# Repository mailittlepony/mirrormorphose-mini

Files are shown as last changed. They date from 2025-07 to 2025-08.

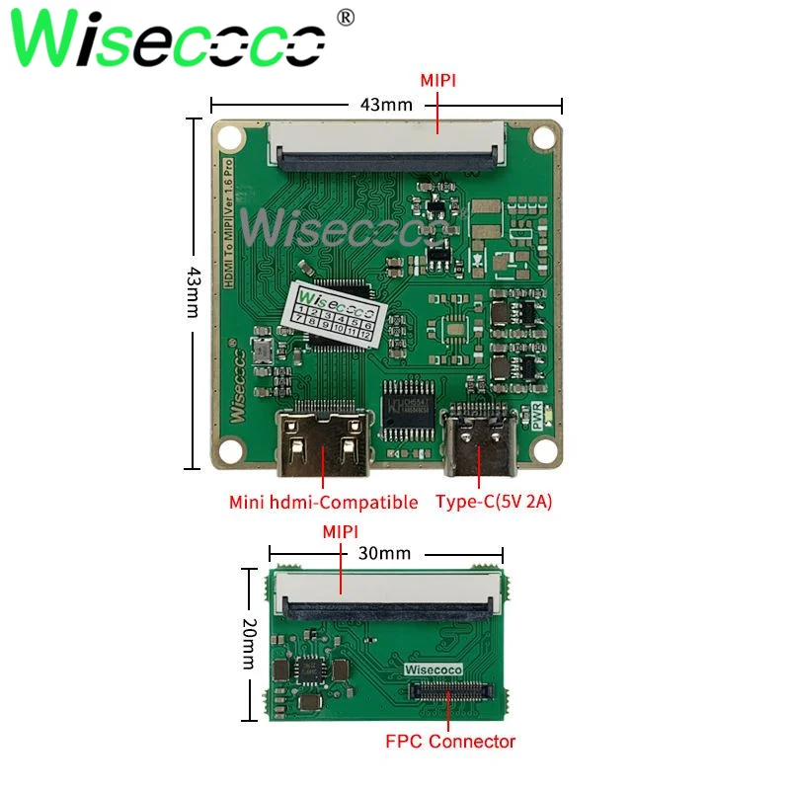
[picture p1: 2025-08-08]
hardware/kicad/display_hdmi_controller/S2047f3f1c8974a16a373eea748ecceee4.webp

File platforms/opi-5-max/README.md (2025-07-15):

This is the platform dependant set up script.

Hardware:
- Orange Pi 5 Max 8GB | Rockchip RK3588 1.8/2.4 GHz | 8 cores | ARMv8
- 5'5 1080x1920 AMOLED HDMI screen
- Orange Pi camera 120° (OV13855)
- SD card

OS:
- DietPi for Orange Pi 5 Max

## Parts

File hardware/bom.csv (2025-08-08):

Item | URL | Quantity | Price Per Unit | Total Price | Vendor
Orange pi 5B max 8GB | https://www.aliexpress.com/item/1005007870048287.html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: | 1 | 18632 | 18632 | Aliexpress
5.5” OLED Full HD screen (option: Full set) | https://ja.aliexpress.com/item/1005004285318699.html?src=google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 | 1 | 10537 | 10537 | Aliexpress
Orange pi camera 80-FF-200mm | https://www.aliexpress.com/item/1005009077854077.html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 | 1 | 3431 | 3431 | Aliexpress
Polyurethane resin 500ml | https://ja.aliexpress.com/item/1005007086008107.html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: | 1 | 2599 | 2599 | Aliexpress
2x 3007 Blower 5V 1W (option 5V- xh2.54) | https://ja.aliexpress.com/item/1005003167479036.html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: | 1 | 1283 | 1283 | Aliexpress
LTC3780 Buck Boost 10A | https://ja.aliexpress.com/item/1005007384626696.html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: | 1 | 1036 | 1036 | Aliexpress
2x 18650 lipo 3.6V 4000mAh | https://ja.aliexpress.com/item/1005006454038524.html?gatewayAdapt=glo2jpn | 1 | 1021 | 1021 | Aliexpress
10x LTC4412 (for power path) | https://ja.aliexpress.com/item/4000112160576.html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: | 1 | 640 | 640 | Aliexpress
25x25x7 Copper Heatsink + pad | https://ja.aliexpress.com/item/1005005311492799.html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: | 1 | 600 | 600 | Aliexpress
10x IRF4905 P-MOSFET-55V -74A 0.02Ohms | https://ja.aliexpress.com/item/1005007142611635.html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: | 1 | 579 | 579 | Aliexpress
HDMI micro connector (option C1) | https://ja.aliexpress.com/item/1005006437300837.html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: | 1 | 434 | 434 | Aliexpress
HDMI connector (option A1) | https://ja.aliexpress.com/item/1005006437300837.html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: | 1 | 430 | 430 | Aliexpress
HDMI ribbon 10cm | https://ja.aliexpress.com/item/1005006437300837.html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: | 1 | 430 | 430 | Aliexpress
SD card 32GB | https://ja.aliexpress.com/item/1005008332881986.html?scm_id=1007.14452.396806.0&scm-url=1007.14452.396806.0 | 1 | 353 | 353 | Aliexpress
Ribbon cable P0.5, 50P, 20cm, reverse direction | https://ja.aliexpress.com/item/1005007079319126.html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: | 1 | 277 | 277 | Aliexpress
100x M2 14mm screw (countersunk head) | https://ja.aliexpress.com/item/33043885403.html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: | 1 | 277 | 277 | Aliexpress
100x M1.2 5mm screw (pan head) | https://ja.aliexpress.com/item/33043885403.html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: | 1 | 233 | 233 | Aliexpress
USB C PD Trigger 20v | https://ja.aliexpress.com/item/1005005461879717.html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: | 1 | 229 | 229 | Aliexpress
2S 20A Balanced BMS | https://ja.aliexpress.com/item/1005006041486774.html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: | 1 | 220 | 220 | Aliexpress
Lipo charger 3A 2S 5-28V input (IP2364) | https://ja.aliexpress.com/item/1005007817048390.html?gatewayAdapt=glo2jpn | 1 | 200 | 200 | Aliexpress

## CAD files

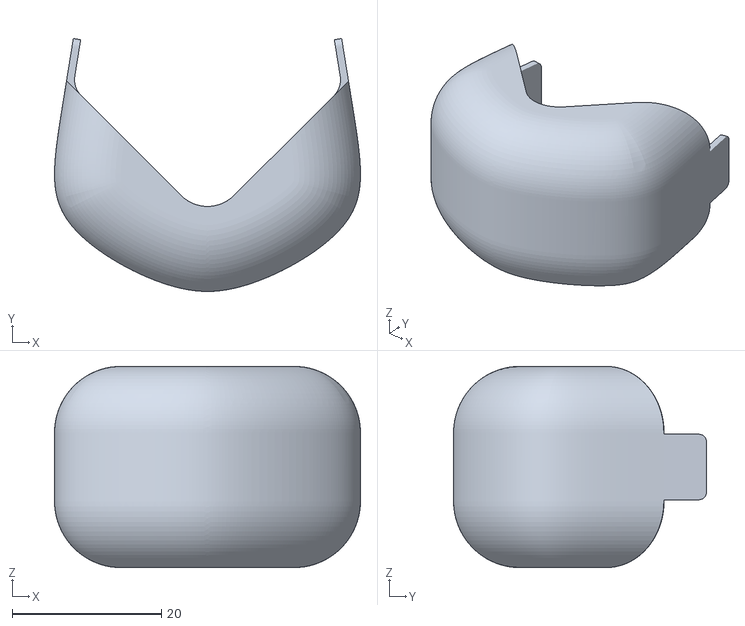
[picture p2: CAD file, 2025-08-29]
hardware/cad/toe.stl
41.1 x 33.9 x 27.0

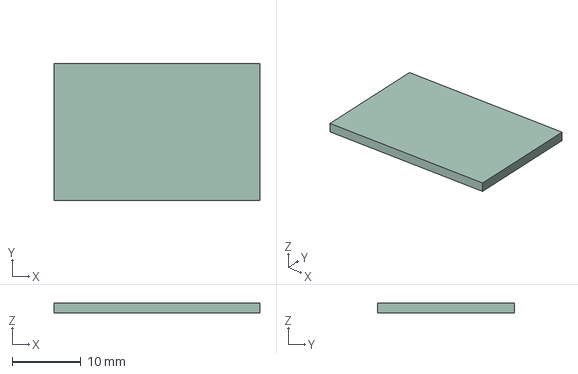
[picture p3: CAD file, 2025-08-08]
hardware/kicad/display_adaptor/display_adaptor.step
30.0 x 20.0 x 1.51 mm

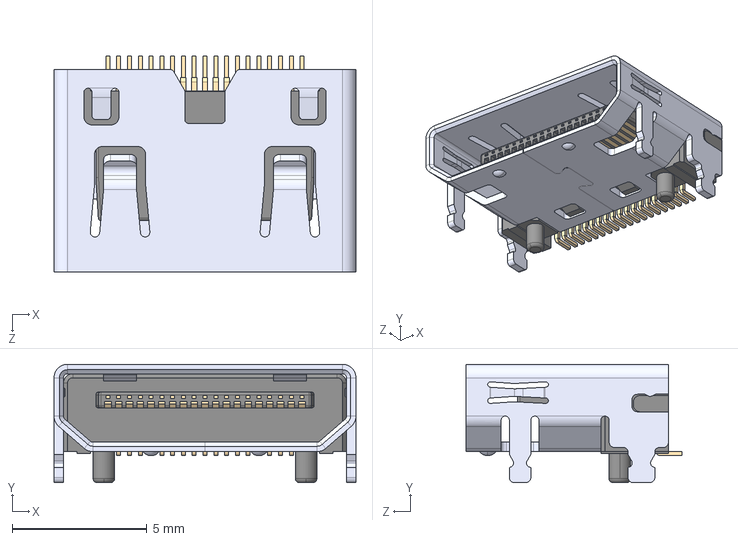
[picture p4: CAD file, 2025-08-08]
hardware/kicad/display_hdmi_controller/3dmodels/690-019-298-903.step
11.2 x 4.39 x 8.00 mm

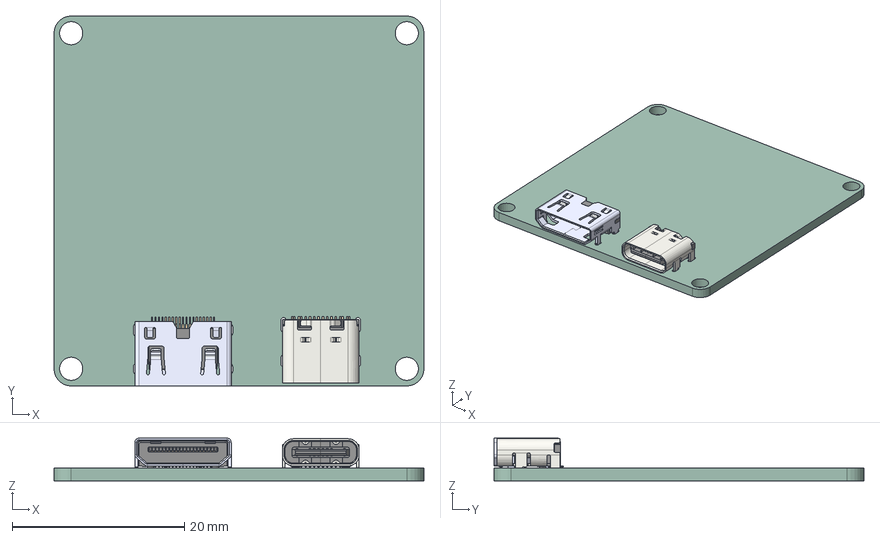
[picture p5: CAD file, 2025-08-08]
hardware/kicad/display_hdmi_controller/display_hdmi_controller.step
43.0 x 43.0 x 4.99 mm
USB_C_Receptacle_GCT_USB4105-xx-A_16P_TopMnt_Horizontal
hdmi_display_kicad_PCB

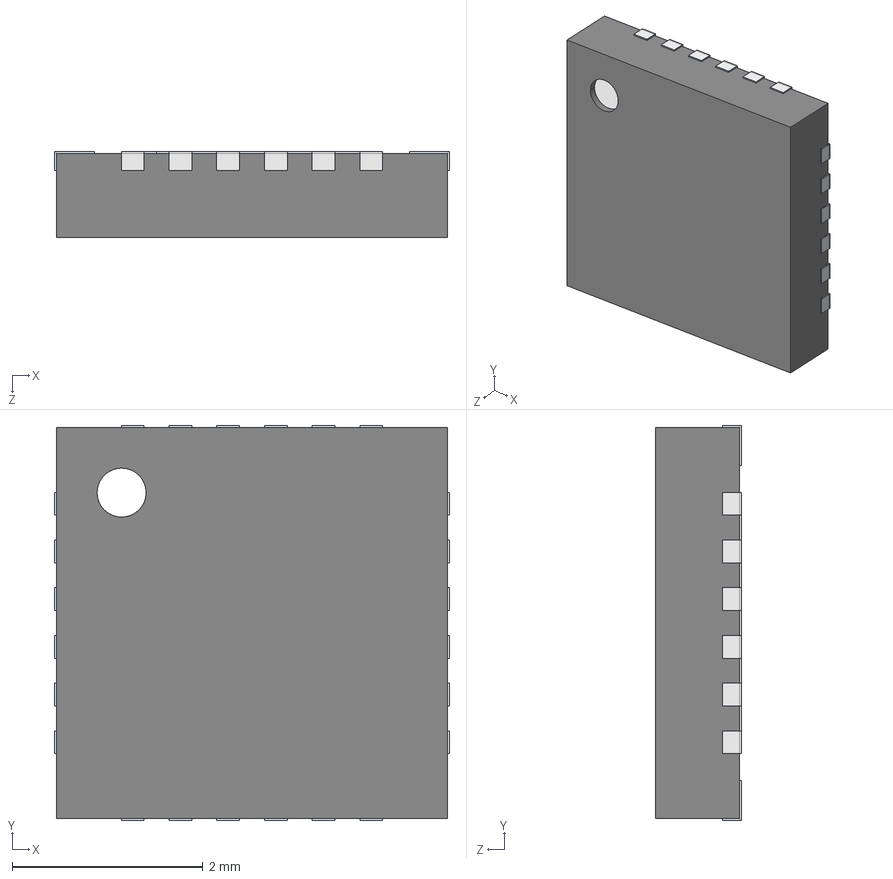
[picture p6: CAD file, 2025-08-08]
hardware/kicad/ip2565charger/3dmodels/QFN 24.STEP
4.14 x 4.14 x 0.9 mm
Open_CASCADE_STEP_translator_6.8_11.2.1.step_Varsay考an
Open_CASCADE_STEP_translator_6.8_11.4.1.step_Varsay考an x 24
Open_CASCADE_STEP_translator_6.8_11.1.step_Varsay考an
Thermal_Shape.step_Varsay考an

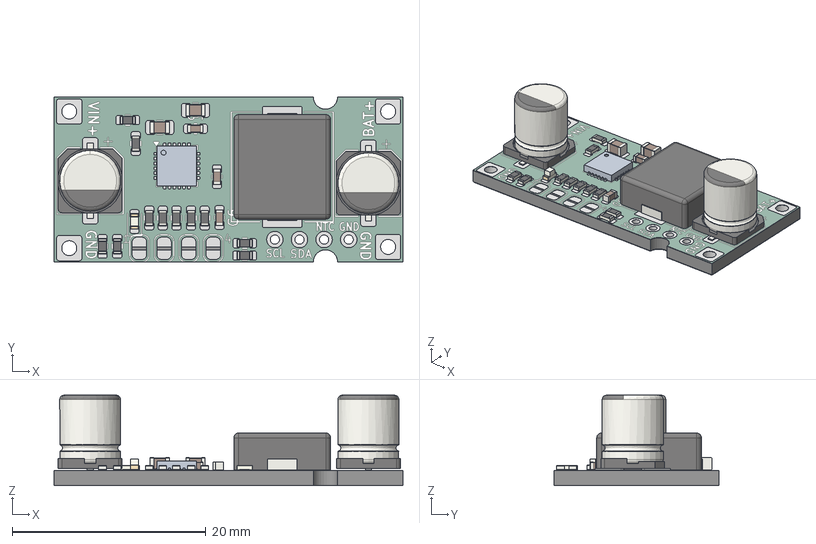
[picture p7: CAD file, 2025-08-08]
hardware/kicad/ip2565charger/ip2565-module.step
36.0 x 17.0 x 9.35 mm
R_0603_1608Metric x 11
CP_Elec_6.3x7.7 x 2
ip2565-module 1.4.1
C_0805_2012Metric x 2
L_APV_APH1040
C_0603_1608Metric x 3
LED_0603_1608Metric
ip2565-module_pad
ip2565-module_silkscreen
ip2565-module_soldermask
ip2565-module_PCB

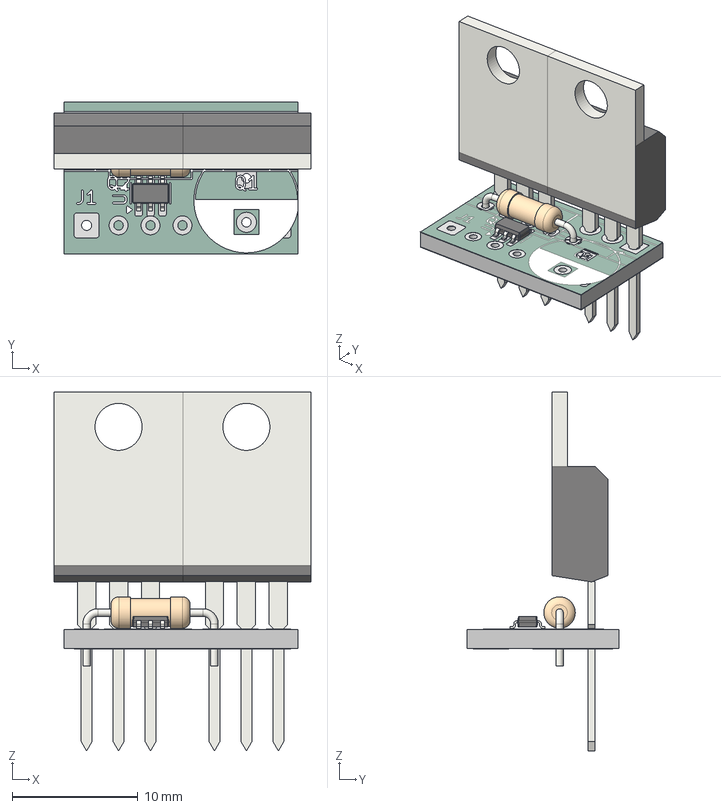
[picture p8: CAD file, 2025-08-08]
hardware/kicad/loadsharing/loadsharing.step
20.4 x 12.1 x 28.5 mm
TSOT-23-6
TO-220-3_Vertical x 2
R_Axial_DIN0207_L6.3mm_D2.5mm_P10.16mm_Horizontal
mirrorminiv2_copper
mirrorminiv2_pad
mirrorminiv2_silkscreen
mirrorminiv2_soldermask
mirrorminiv2_PCB

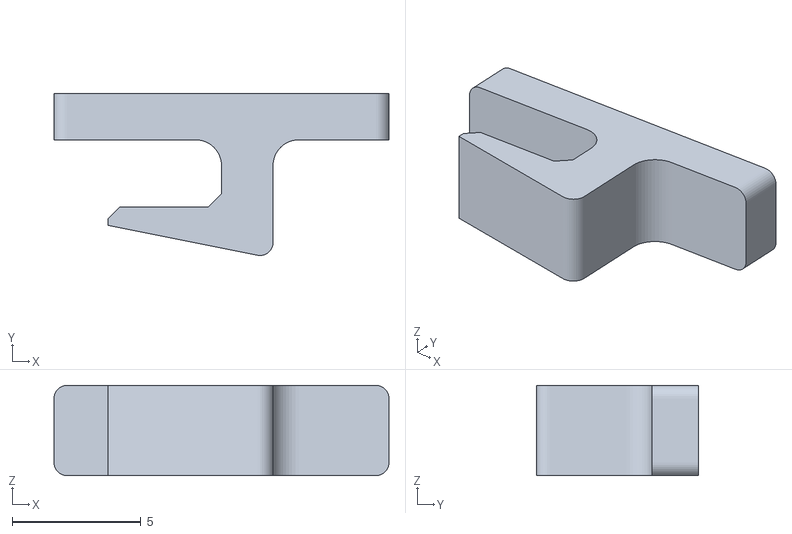
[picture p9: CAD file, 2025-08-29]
hardware/cad/snap-male-smooth.stl
13.0 x 6.29 x 3.50

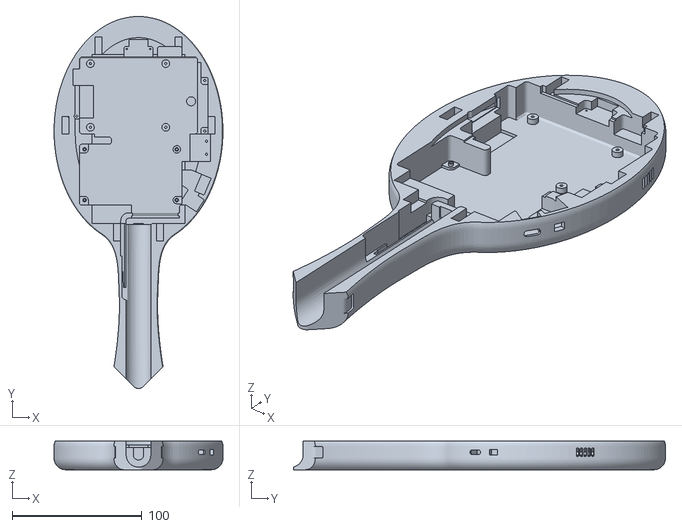
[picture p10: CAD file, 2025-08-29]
hardware/cad/bottom.stl
130.0 x 286.3 x 22.0

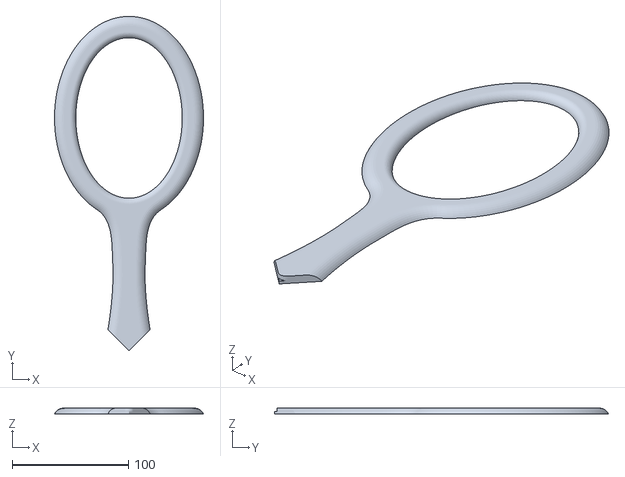
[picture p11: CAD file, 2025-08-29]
hardware/cad/top.stl
128.2 x 287.4 x 5.00

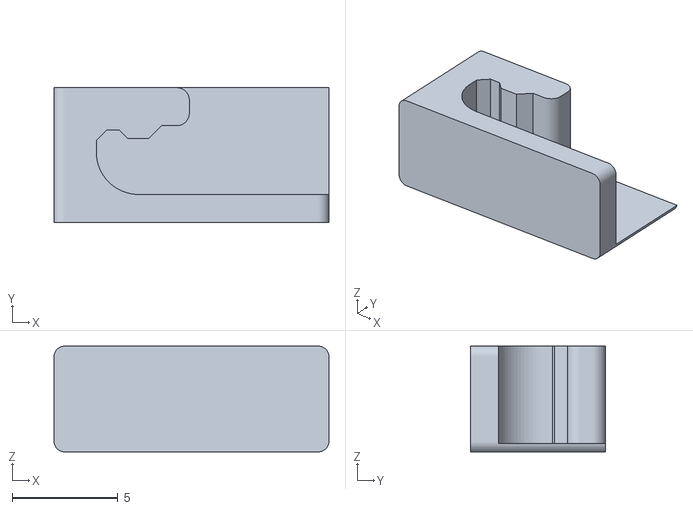
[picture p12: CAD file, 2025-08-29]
hardware/cad/snap-static.stl
13.0 x 6.37 x 5.00

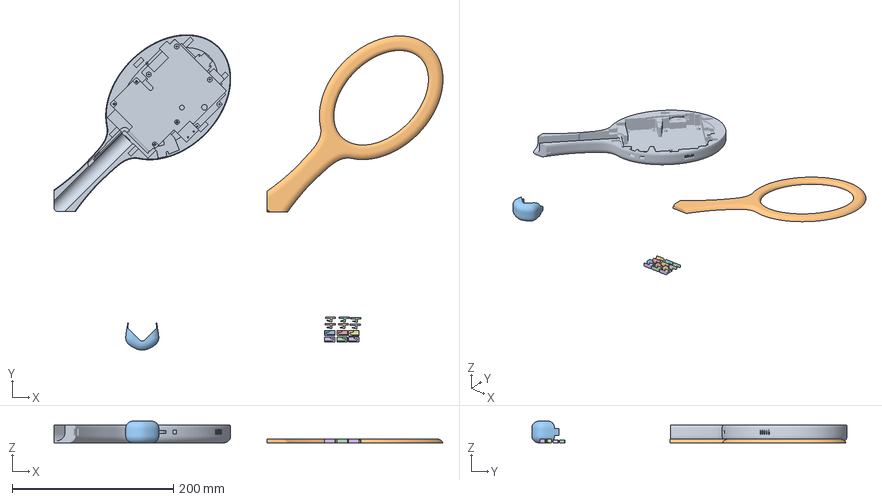
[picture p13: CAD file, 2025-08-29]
hardware/cad/mirrormini_ender3v3ke_orca.3mf
482.0 x 390.9 x 27.0 mm
bottom.stl
top.stl
toe.stl
snap-male-smooth.stl x 4
snap-male.stl x 2
snap-static.stl x 6

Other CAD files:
hardware/cad/snap-male.stl

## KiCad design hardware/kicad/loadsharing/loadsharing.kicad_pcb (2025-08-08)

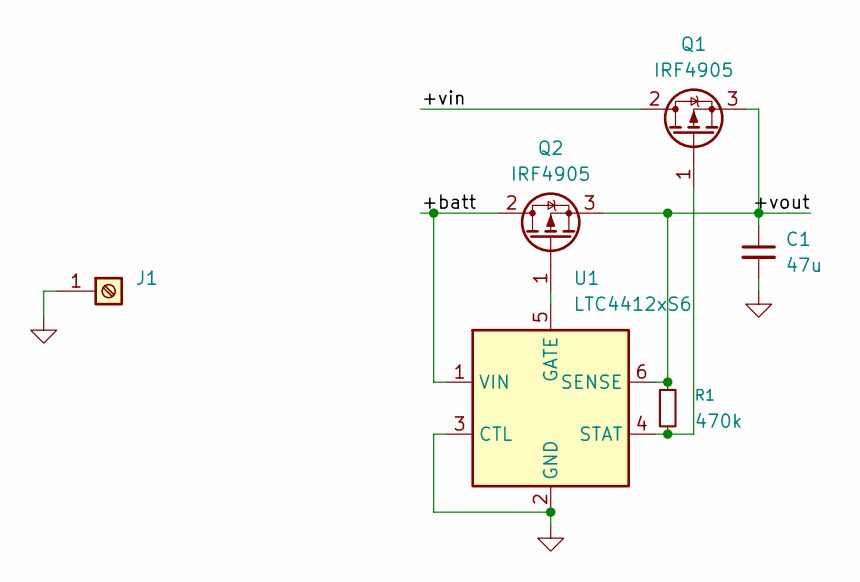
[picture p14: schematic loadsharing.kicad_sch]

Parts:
C1: 47u; CP_Radial_D8.0mm_P3.50mm
J1: Screw_Terminal_01x01; SolderWire-0.25sqmm_1x01_D0.65mm_OD2mm
Q1, Q2: IRF4905; TO-220-3_Vertical
R1: 470k; R_Axial_DIN0207_L6.3mm_D2.5mm_P10.16mm_Horizontal
U1: LTC4412xS6; TSOT-23-6

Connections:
/+batt: Q2.2 (D), U1.1 (VIN)
/+vin: Q1.2 (D)
/+vout: C1.1, Q1.3 (S), Q2.3 (S), R1.1, U1.6 (SENSE)
GND: C1.2, J1.1, U1.2 (GND), U1.3 (CTL)
unnamed: Q1.1 (G), R1.2, U1.4 (STAT)
unnamed: Q2.1 (G), U1.5 (GATE)

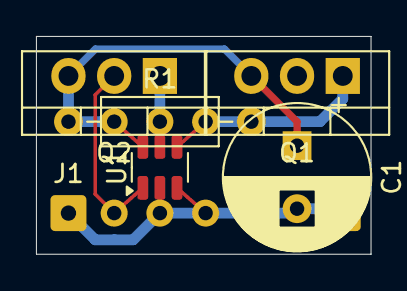
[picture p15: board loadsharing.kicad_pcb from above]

Board: 2 copper layers, 18.6 x 12.1 mm, 6 parts (0 on the bottom side), 5 nets.

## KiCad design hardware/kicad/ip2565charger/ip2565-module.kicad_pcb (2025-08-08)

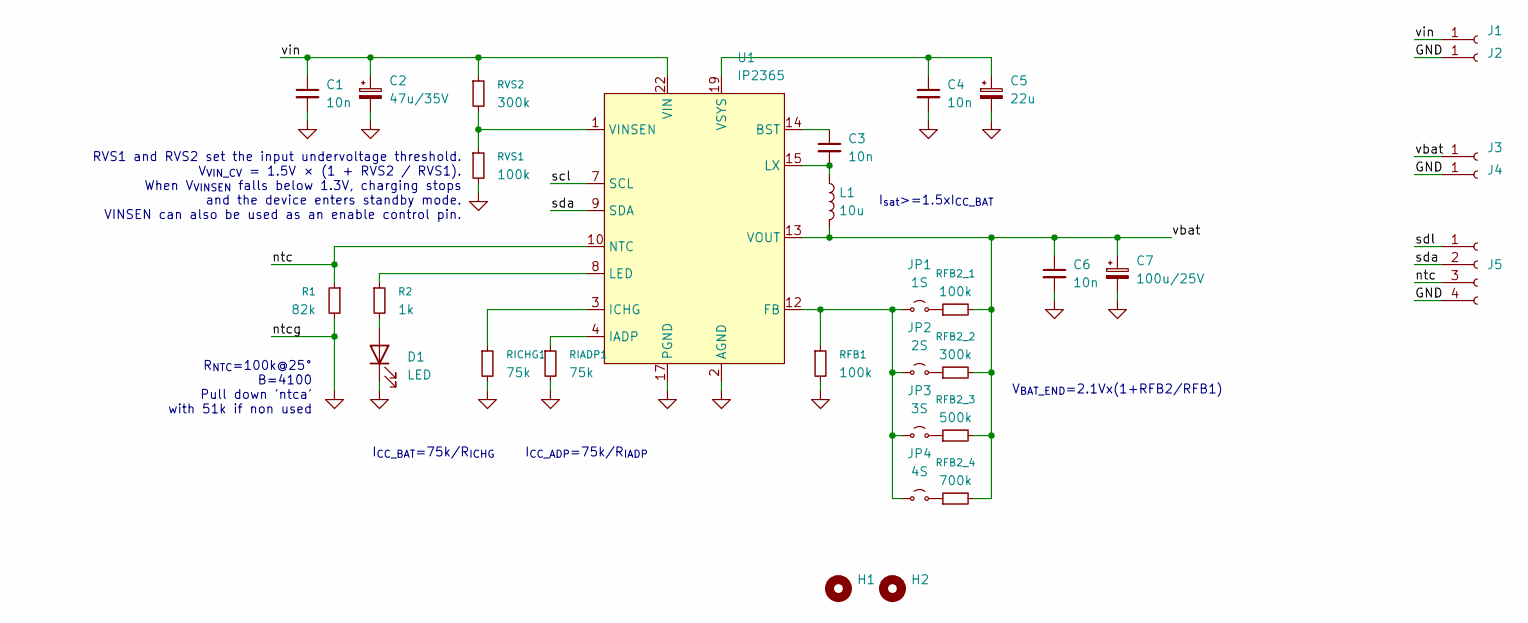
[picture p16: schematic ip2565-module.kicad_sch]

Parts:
C1: 10n; C_0805_2012Metric
C2: 47u/35V; CP_Elec_6.3x7.7
C3, C4, C6: 10n; C_0603_1608Metric
C5: 22u; C_0805_2012Metric
C7: 100u/25V; CP_Elec_6.3x7.7
D1: LED; LED_0603_1608Metric
H1, H2: MountingHole; MountingHole_2.5mm
J1, J2, J3, J4: SolderWire-0.75sqmm_1x01_D1.25mm_OD2.3mm
J5: PinHeader_1x04_P2.54mm_Vertical
JP1: 1S; SolderJumper-2_P1.3mm_Open_RoundedPad1.0x1.5mm
JP2: 2S; SolderJumper-2_P1.3mm_Open_RoundedPad1.0x1.5mm
JP3: 3S; SolderJumper-2_P1.3mm_Open_RoundedPad1.0x1.5mm
JP4: 4S; SolderJumper-2_P1.3mm_Open_RoundedPad1.0x1.5mm
L1: 10u; L_APV_APH1040
R1: 82k; R_0603_1608Metric
R2: 1k; R_0603_1608Metric
RFB1, RFB2_1: 100k; R_0603_1608Metric
RFB2_2: 300k; R_0603_1608Metric
RFB2_3: 500k; R_0603_1608Metric
RFB2_4: 700k; R_0603_1608Metric
RIADP1: 75k; R_0603_1608Metric
RICHG1: 75k; R_0603_1608Metric
RVS1: 100k; R_0603_1608Metric
RVS2: 300k; R_0603_1608Metric
U1: IP2365; QFN-24-1EP_4x4mm_P0.5mm_EP2.65x2.65mm_ThermalVias

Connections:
/ntc: J5.3, R1.1, U1.10 (NTC)
/scl: U1.7 (SCL)
/sda: J5.2, U1.9 (SDA)
/sdl: J5.1
/vbat: C6.1, C7.1, J3.1, L1.2, RFB2_1.2, RFB2_2.2, RFB2_3.2, RFB2_4.2, U1.13 (VOUT)
/vin: C1.1, C2.1, J1.1, RVS2.1, U1.22 (VIN), U1.23 (VIN), U1.24 (VIN)
GND: C1.2, C2.2, C4.2, C5.2, C6.2, C7.2, D1.1 (K), J2.1, J4.1, J5.4, R1.2, RFB1.2, RIADP1.2, RICHG1.2, RVS1.2, U1.2 (AGND), U1.11 (AGND), U1.17 (PGND), U1.18 (PGND), U1.25 (EPAD)
unnamed: C3.2, L1.1, U1.15 (LX), U1.16 (LX)
unnamed: C4.1, C5.1, U1.19 (VSYS), U1.20 (VSYS), U1.21 (VSYS)
unnamed: D1.2 (A), R2.2
unnamed: JP1.1 (A), JP2.1 (A), JP3.1 (A), JP4.1 (A), RFB1.1, U1.12 (FB)
unnamed: JP1.2 (B), RFB2_1.1
unnamed: JP2.2 (B), RFB2_2.1
unnamed: JP3.2 (B), RFB2_3.1
unnamed: JP4.2 (B), RFB2_4.1
unnamed: C3.1, U1.14 (BST)
unnamed: RIADP1.1, U1.4 (IADP)
unnamed: RICHG1.1, U1.3 (ICHG)
unnamed: R2.1, U1.8 (LED)
unnamed: U1.5 (NC), U1.6 (NC)
unnamed: RVS1.1, RVS2.2, U1.1 (VINSEN)

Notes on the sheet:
RVS1 and RVS2 set the input undervoltage threshold. V_{VIN_CV} = 1.5V × (1 + RVS2 / RVS1). When V_{VINSEN} falls below 1.3V, charging stops and the device enters standby mode. VINSEN can also be used as an enable control pin.
R_{NTC}=100k@25° B=4100 Pull down 'ntca' with 51k if non used
V_{BAT_END}=2.1Vx(1+RFB2/RFB1)
I_{CC_ADP}=75k/R_{IADP}
I_{CC_BAT}=75k/R_{ICHG}
I_{sat}>=1.5xI_{CC_BAT}

Board: 2 copper layers, 32 parts (0 on the bottom side), 19 nets, no tracks yet.

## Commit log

2025-08-08 add kicad pcb
    [690-019-298-903.step, QFN 24.STEP, display_adaptor.kicad_pcb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]
2025-08-08 add bom
    [bom.csv]
2025-08-29 add cad, elec, bom
    [bottom.stl, mirrormini.kicad_pcb, mirrormini.kicad_sch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]
2025-08-29 serve camera frame
